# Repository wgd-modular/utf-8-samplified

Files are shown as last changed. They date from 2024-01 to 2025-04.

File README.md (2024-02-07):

# utf-8-samplified

An Arduino nano sample based 8-channel drum module for the eurorack format.

For more information on the project take a look into the [wiki](https://github.com/wgd-modular/utf-8-samplified/wiki)!



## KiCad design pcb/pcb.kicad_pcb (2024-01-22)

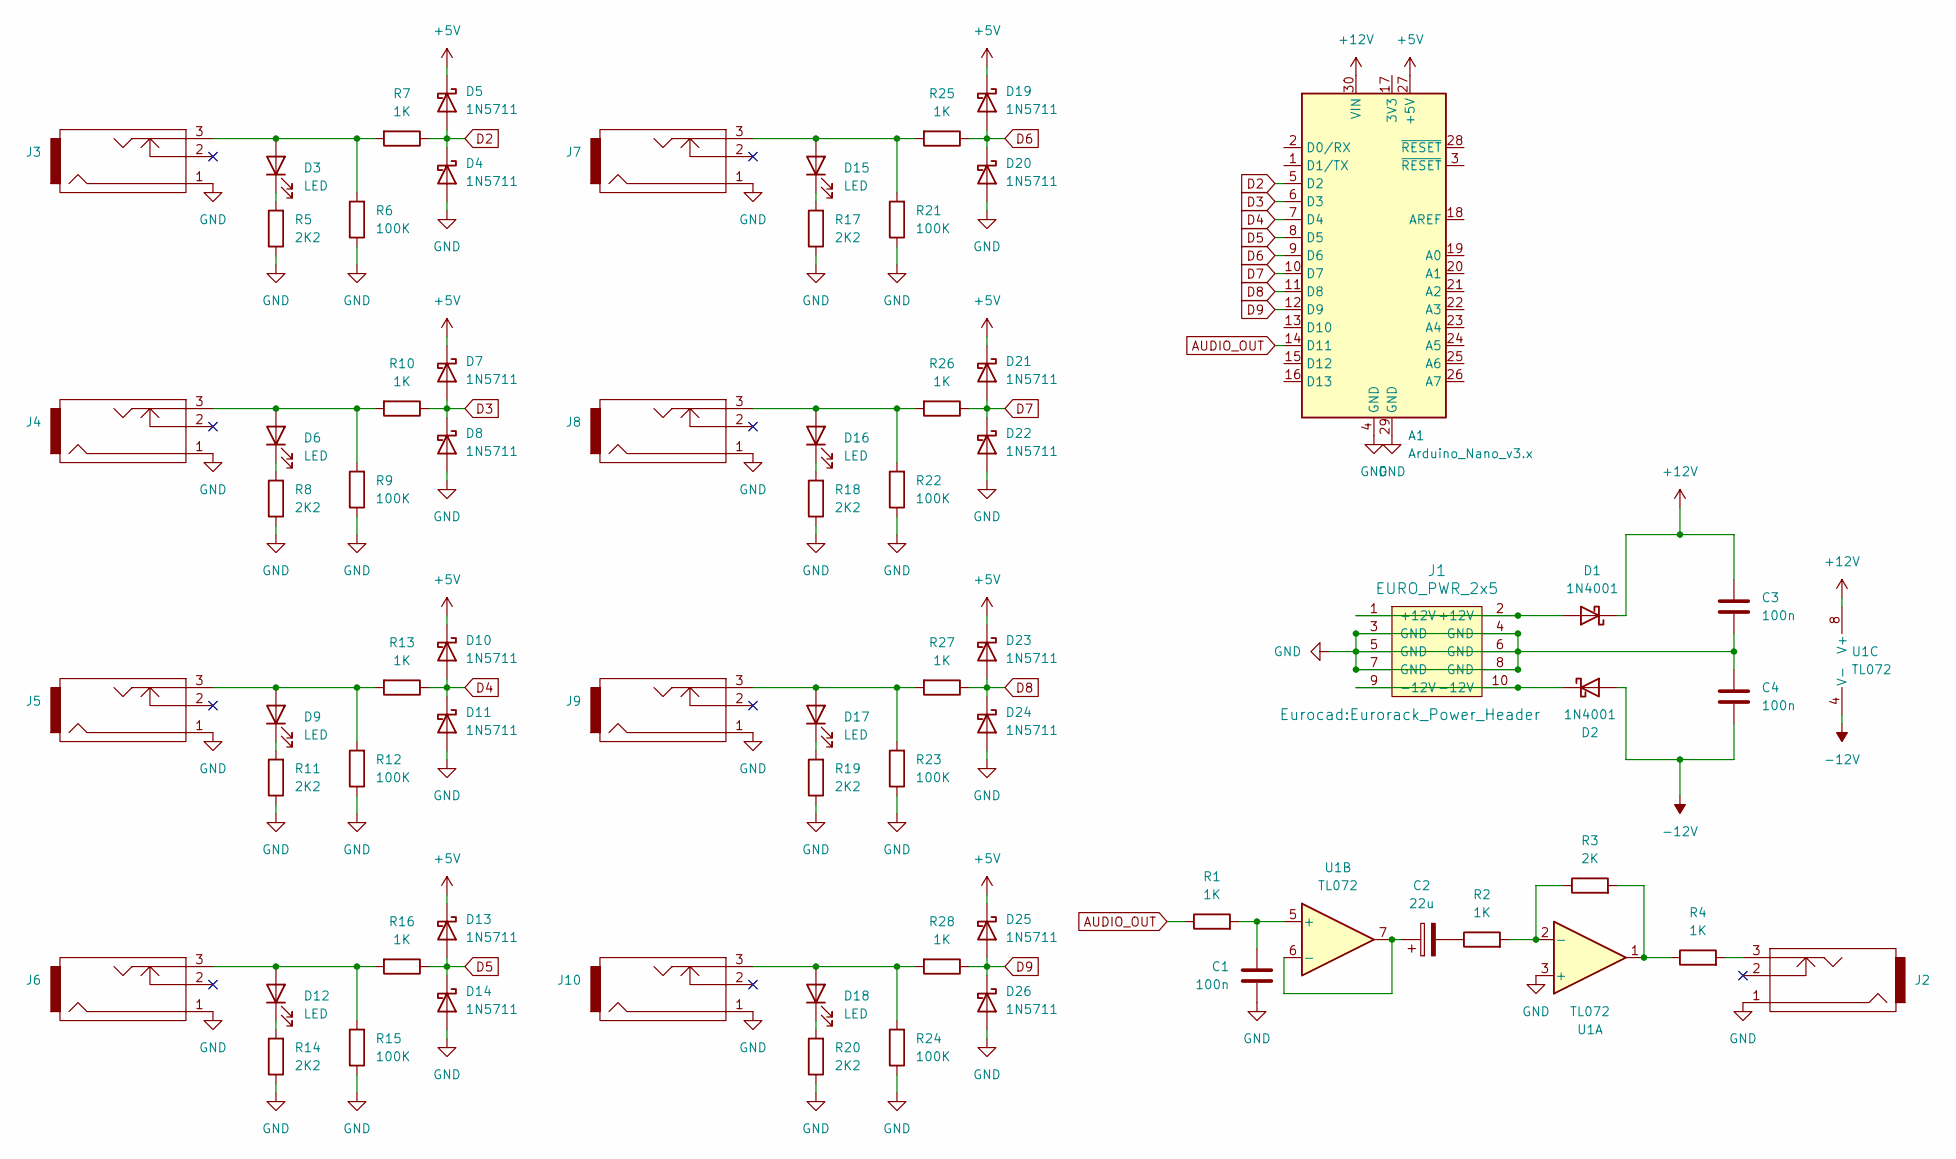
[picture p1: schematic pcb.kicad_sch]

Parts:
A1: Arduino_Nano_v3.x; Arduino_Nano
C1, C3, C4: 100n; C_Rect_L7.2mm_W3.0mm_P5.00mm_FKS2_FKP2_MKS2_MKP2
C2: 22u; CP_Radial_D5.0mm_P2.50mm
D1, D2: 1N4001; D_DO-41_SOD81_P10.16mm_Horizontal
D3, D6, D9, D12, D15, D16, D17, D18: LED; LED_D3.0mm
D4, D5, D7, D8, D10, D11, D13, D14, D19, D20, D21, D22, D23, D24, D25, D26: 1N5711; D_DO-35_SOD27_P7.62mm_Horizontal
J1: EURO_PWR_2x5; Eurorack_Power_Header
J2, J3, J4, J5, J6, J7, J8, J9, J10: PJ301M-12
R1, R2, R4, R7, R10, R13, R16, R25, R26, R27, R28: 1K; R_Axial_DIN0207_L6.3mm_D2.5mm_P7.62mm_Horizontal
R3: 2K; R_Axial_DIN0207_L6.3mm_D2.5mm_P7.62mm_Horizontal
R5, R8, R11, R14, R17, R18, R19, R20: 2K2; R_Axial_DIN0207_L6.3mm_D2.5mm_P7.62mm_Horizontal
R6, R9, R12, R15, R21, R22, R23, R24: 100K; R_Axial_DIN0207_L6.3mm_D2.5mm_P7.62mm_Horizontal
U1: TL072; DIP-8_W7.62mm

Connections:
+5V: A1.27 (+5V), D5.1 (K), D7.1 (K), D10.1 (K), D13.1 (K), D19.1 (K), D21.1 (K), D23.1 (K), D25.1 (K)
+12V: A1.30 (VIN), C3.1, D1.1 (K), U1.8 (V+)
-12V: C4.2, D2.2 (A), U1.4 (V-)
AUDIO_OUT: A1.14 (D11), R1.1
D2: A1.5 (D2), D4.1 (K), D5.2 (A), R7.1
D3: A1.6 (D3), D7.2 (A), D8.1 (K), R10.1
D4: A1.7 (D4), D10.2 (A), D11.1 (K), R13.1
D5: A1.8 (D5), D13.2 (A), D14.1 (K), R16.1
D6: A1.9 (D6), D19.2 (A), D20.1 (K), R25.1
D7: A1.10 (D7), D21.2 (A), D22.1 (K), R26.1
D8: A1.11 (D8), D23.2 (A), D24.1 (K), R27.1
D9: A1.12 (D9), D25.2 (A), D26.1 (K), R28.1
GND: A1.4 (GND), A1.29 (GND), C1.2, C3.2, C4.1, D4.2 (A), D8.2 (A), D11.2 (A), D14.2 (A), D20.2 (A), D22.2 (A), D24.2 (A), D26.2 (A), J1.3 (GND), J1.4 (GND), J1.5 (GND), J1.6 (GND), J1.7 (GND), J1.8 (GND), J2.1, J3.1, J4.1, J5.1, J6.1, J7.1, J8.1, J9.1, J10.1, R5.1, R6.1, R8.1, R9.1, R11.1, R12.1, R14.1, R15.1, R17.1, R18.1, R19.1, R20.1, R21.1, R22.1, R23.1, R24.1, U1.3 (+)
unnamed: C2.2, R2.1
unnamed: D1.2 (A), J1.1 (+12V), J1.2 (+12V)
unnamed: D2.1 (K), J1.9 (-12V), J1.10 (-12V)
unnamed: D3.2 (A), J3.3, R6.2, R7.2
unnamed: D3.1 (K), R5.2
unnamed: D6.2 (A), J4.3, R9.2, R10.2
unnamed: D6.1 (K), R8.2
unnamed: D9.2 (A), J5.3, R12.2, R13.2
unnamed: D9.1 (K), R11.2
unnamed: D12.2 (A), J6.3, R15.2, R16.2
unnamed: D12.1 (K), R14.2
unnamed: D15.2 (A), J7.3, R21.2, R25.2
unnamed: D15.1 (K), R17.2
unnamed: D16.2 (A), J8.3, R22.2, R26.2
unnamed: D16.1 (K), R18.2
unnamed: D17.2 (A), J9.3, R23.2, R27.2
unnamed: D17.1 (K), R19.2
unnamed: D18.2 (A), J10.3, R24.2, R28.2
unnamed: D18.1 (K), R20.2
unnamed: J2.3, R4.2
unnamed: R3.2, R4.1, U1.1
unnamed: R2.2, R3.1, U1.2 (-)
unnamed: C1.1, R1.2, U1.5 (+)
unnamed: C2.1, U1.6 (-), U1.7

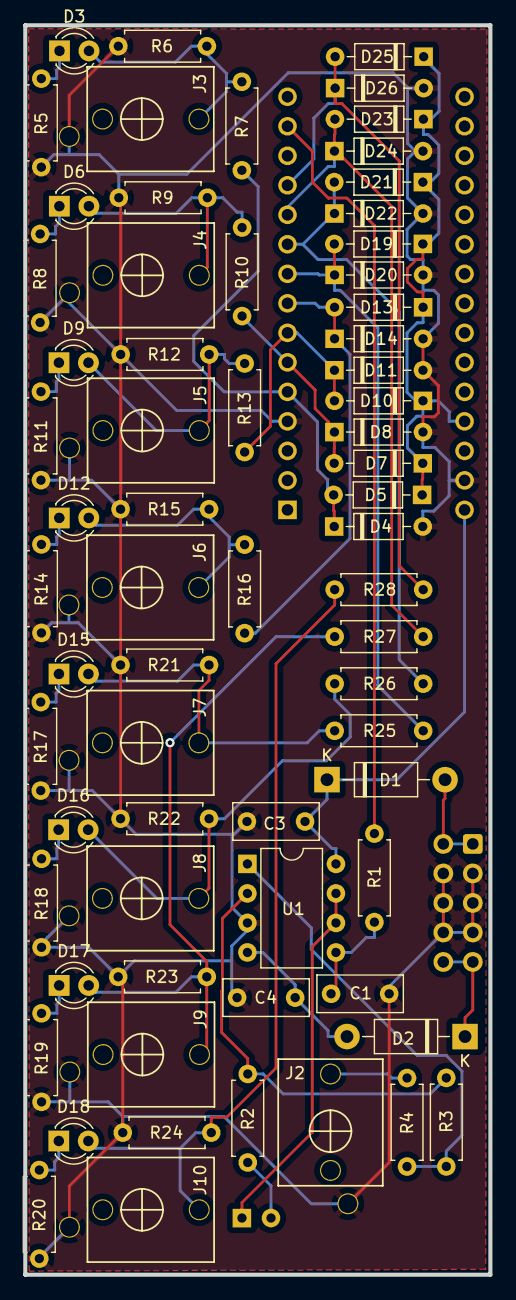
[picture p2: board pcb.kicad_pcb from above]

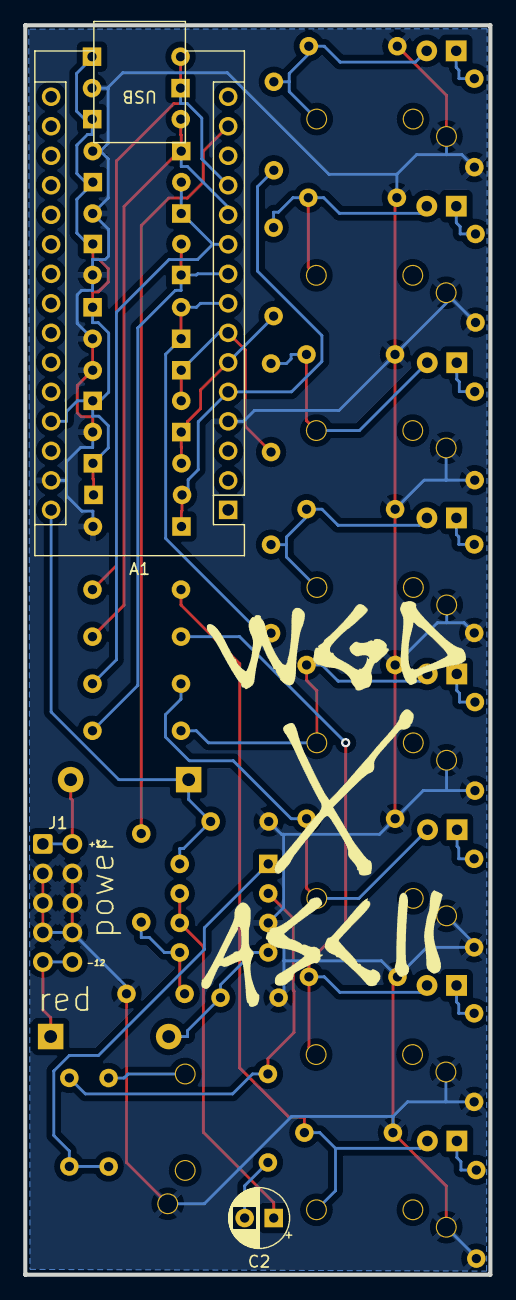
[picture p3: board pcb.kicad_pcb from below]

Board: 2 copper layers, 40.0 x 107.5 mm, 70 parts (3 on the bottom side), 37 nets.

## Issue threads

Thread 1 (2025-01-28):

Running with a LGT8F328P rather than a nano.

poetaster, 2025-01-28:
Hi! I just purchased a couple of boards (kleinanzeigen.de) and am looking forward to building this. Most of my nano projects I've moved to using a LGT8F328P running at 32MHZ (also has an 8 bit DAC and one more 16bit timer). I'm wondering if you're interested in that? I'm going to try to see how it runs, but obviously would need resample? Might be nice to have a version of utf-8 using a 'proper dac', maybe?

If you're interested, I can send you a board. There's lots of really good documenation at: https://wolles-elektronikkiste.de/en/lgt8f328p-lqfp32-boards

Thanks for the fun project!

fxwiegand, 2025-01-28:
Hi! Thanks for your interest in the project and for sharing your experience with the LGT8F328P. I’ve actually tried using these boards before, but unfortunately, I found them to be quite unreliable, so I didn’t dive deeper into them. I also discussed this with the folks at Modulove (https://modulove.io/), and they’ve had similar experiences with the LGT8F328P.

That said, it’s interesting to hear you’ve had success with them. If you do end up experimenting and resampling, I’d be curious to hear your results. Thanks again for the offer and for the kind words about the project!

poetaster, 2025-01-28:
> Hi! Thanks for your interest in the project and for sharing your experience with the LGT8F328P. I’ve actually tried using these boards before, but unfortunately, I found them to be quite unreliable, so I didn’t dive deeper into them. I also discussed this with the folks at Modulove (https://modulove.io/), and they’ve had similar experiences with the LGT8F328P.

Ah, that could be an issue with the supplier. I have a good one :) I have had one dodgy batch (3 out of 10), but have about 30 pieces (and several prototypes in use at home) in product with no complaints. I could send a known working piece or two.

> That said, it’s interesting to hear you’ve had success with them. If you do end up experimenting and resampling, I’d be curious to hear your results. Thanks again for the offer and for the kind words about the project!

I'll let you know how it stacks up when I've finished and report here. And thanks for making modules!

fxwiegand, 2025-01-29:
> I'll let you know how it stacks up when I've finished and report here. And thanks for making modules!

Actually very much looking forward to hear about your results with the LGT8F328P! Going to close this here but please keep me in the loop when you have any news.

poetaster, 2025-01-30:
Ok! So the build went smoothly. I directly went with an LGT8F328P and it all (tried all three kits), just works :) It looks like the sample rate is 40Khz and one of the timers is running at that rate. I'll try some of my own samples when I get a chance.

One note is that the module is very quiet in comparison to everything else I have in the rack.

poetaster, 2025-01-30:
Ok! So the build went smoothly. I directly went with an LGT8F328P and it all (tried all three kits), just works :) It looks like the sample rate is 40Khz and one of the timers is running at that rate. I'll try some of my own samples when I get a chance.

One note is that the module is very quiet in comparison to everything else I have in the rack.

poetaster, 2025-01-30:
> You could increase the value of R3 in the feedback loop of the op-amp to increase the gain!

R3. Bottom rightmost under D2, right?  It's 2K now, so maybe a 3.3 or  4.7K  for a start?

fxwiegand, 2025-01-30:
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

In theory 2K sets the gain of the op-amp to 2 so 3K would main a gain of 3.

poetaster, 2025-01-30:
> In theory 2K sets the gain of the op-amp to 2 so 3K would main a gain of 3.

Ok, I'll give it a go. I'll also try a resistor in parallel on one of the leds to see how that works.

poetaster, 2025-01-30:
Ok, I went with 3.9K, a notable improvement with a minimal amount more noise (4.7 was getting noisy).  Thanks!

fxwiegand, 2025-01-30:
> Ok, I went with 3.9K, a notable improvement with a minimal amount more noise (4.7 was getting noisy). Thanks!

Great to hear it worked!

Closed 2025-01-29.

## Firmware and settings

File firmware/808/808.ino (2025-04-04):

// dsp-D8 Drum Chip (c) DSP Synthesizers 2015
// Free for non commercial use

// Modified by ASCII to be triggered by digital inputs (2024)


#include <avr/interrupt.h>
#include <avr/io.h>
#include <avr/pgmspace.h>
#include "drum_samples.h"

#ifndef cbi
#define cbi(sfr, bit) (_SFR_BYTE(sfr) &= ~_BV(bit))
#endif
#ifndef sbi
#define sbi(sfr, bit) (_SFR_BYTE(sfr) |= _BV(bit))
#endif

// Standard Arduino Pins
#define digitalPinToPortReg(P) \
  (((P) >= 0 && (P) <= 7) ? &PORTD : (((P) >= 8 && (P) <= 13) ? &PORTB : &PORTC))
#define digitalPinToDDRReg(P) \
  (((P) >= 0 && (P) <= 7) ? &DDRD : (((P) >= 8 && (P) <= 13) ? &DDRB : &DDRC))
#define digitalPinToPINReg(P) \
  (((P) >= 0 && (P) <= 7) ? &PIND : (((P) >= 8 && (P) <= 13) ? &PINB : &PINC))
#define digitalPinToBit(P) \
  (((P) >= 0 && (P) <= 7) ? (P) : (((P) >= 8 && (P) <= 13) ? (P) - 8 : (P) - 14))

#define digitalReadFast(P) bitRead(*digitalPinToPINReg(P), digitalPinToBit(P))

#define digitalWriteFast(P, V) bitWrite(*digitalPinToPortReg(P), digitalPinToBit(P), (V))

const unsigned char PS_128 = (1 << ADPS2) | (1 << ADPS1) | (1 << ADPS0);

byte inputs[8] = { 2, 3, 4, 5, 6, 7, 8, 9 }; // could add , 8, 9 here..
bool prevInputStates[8] = { false, false, false, false, false, false, false, false }; // and increase this array size to 8

//--------- Ringbuf parameters ----------
uint8_t Ringbuffer[256];
uint8_t RingWrite = 0;
uint8_t RingRead = 0;
volatile uint8_t RingCount = 0;
<<<<<<< HEAD
int speakerPin = 11;
=======
>>>>>>> a4939a3c1647ea02244b6e4c8038a8c222b82560

//-----------------------------------------

ISR(TIMER1_COMPA_vect) {

  //-------------------  Ringbuffer handler -------------------------

  if (RingCount) {                            //If entry in FIFO..
    OCR2A = Ringbuffer[(RingRead++)];          //Output LSB of 16-bit DAC
    RingCount--;
  }

  //-----------------------------------------------------------------

}

bool debug = false;

<<<<<<< HEAD
/*
 * An example of how you get rid of click at end of play
 * We just make sure to not wrap around the samplecnt
ISR(TIMER1_COMPA_vect) {
   if (sample >= sounddata_length) {
       if (sample == sounddata_length + lastSample) {
           stopPlayback();
       }
       else {
           if(speakerPin==11){
               // Ramp down to zero to reduce the click at the end of playback.
               OCR2A = sounddata_length + lastSample - sample;
           } else {
               OCR2B = sounddata_length + lastSample - sample; // pin 3
           }
       }
   }
   else {
       if(speakerPin==11){
           OCR2A = Ringbuffer[(RingRead++)]; //pgm_read_byte(&sounddata_data[sample]);
       } else {
           OCR2B = Ringbuffer[(RingRead++)]; //pgm_read_byte(&sounddata_data[sample]); //pin 3
       }
   }
   RingCount--; // ++sample;
}
void stopPlayback()
{
   // Disable playback per-sample interrupt.
   TIMSK1 &= ~_BV(OCIE1A);
   // Disable the per-sample timer completely.
   TCCR1B &= ~_BV(CS10);
   // Disable the PWM timer.
   TCCR2B &= ~_BV(CS10);
   digitalWrite(speakerPin, LOW);
   
}
*/

bool debug = false;



void setup()
{
  OSCCAL = 0xFF;

=======
void setup()
{
  OSCCAL = 0xFF;

>>>>>>> a4939a3c1647ea02244b6e4c8038a8c222b82560
  for (byte i = 0; i < 6; i++) {
    pinMode(inputs[i], INPUT);
  }

  //8-bit PWM DAC pin
  pinMode(11, OUTPUT);

  // Set up Timer 1 to send a sample every interrupt.
  cli();
  // Set CTC mode
  // Have to set OCR1A *after*, otherwise it gets reset to 0!
  TCCR1B = (TCCR1B & ~_BV(WGM13)) | _BV(WGM12);
  TCCR1A = TCCR1A & ~(_BV(WGM11) | _BV(WGM10));
  // No prescaler
  TCCR1B = (TCCR1B & ~(_BV(CS12) | _BV(CS11))) | _BV(CS10);
  // Set the compare register (OCR1A).
  // OCR1A is a 16-bit register, so we have to do this with
  // interrupts disabled to be safe.
  //OCR1A = F_CPU / SAMPLE_RATE;
  // Enable interrupt when TCNT1 == OCR1A
  TIMSK1 |= _BV(OCIE1A);
  OCR1A = 400; //40KHz Samplefreq

  // Set up Timer 2 to do pulse width modulation on D11

  // Use internal clock (datasheet p.160)
  ASSR &= ~(_BV(EXCLK) | _BV(AS2));

  // Set fast PWM mode  (p.157)
  TCCR2A |= _BV(WGM21) | _BV(WGM20);
  TCCR2B &= ~_BV(WGM22);

  // Do non-inverting PWM on pin OC2A (p.155)
  // On the Arduino this is pin 11.
  TCCR2A = (TCCR2A | _BV(COM2A1)) & ~_BV(COM2A0);
  TCCR2A &= ~(_BV(COM2B1) | _BV(COM2B0));
  // No prescaler (p.158)
  TCCR2B = (TCCR2B & ~(_BV(CS12) | _BV(CS11))) | _BV(CS10);

  // Set initial pulse width to the first sample.
  OCR2A = 128;

  //set timer0 interrupt at 61Hz
  TCCR0A = 0;// set entire TCCR0A register to 0
  TCCR0B = 0;// same for TCCR0B
  TCNT0  = 0;//initialize counter value to 0
  // set compare match register for 62hz increments
  OCR0A = 255;// = 61Hz
  // turn on CTC mode
  TCCR0A |= (1 << WGM01);
  // Set CS01 and CS00 bits for prescaler 1024
  TCCR0B |= (1 << CS02) | (0 << CS01) | (1 << CS00);  //1024 prescaler

  TIMSK0 = 0;


  // set up the ADC
  ADCSRA &= ~PS_128;  // remove bits set by Arduino library
  // Choose prescaler PS_128.
  ADCSRA |= PS_128;
  ADMUX = 64;
  sbi(ADCSRA, ADSC);
  if (debug) {
    Serial.begin(115200);
    Serial.println("Modified [Jan Ostman] dsp-D8:");
    Serial.println("https://janostman.wordpress.com/the-dsp-d8-drum-chip-source-code/");
    Serial.println("Press asdfjkl; to play the drums.");
  }

  sei();
}

uint8_t phaccBD, phaccCH, phaccCL, phaccCR, phaccOH, phaccRD, phaccRS, phaccSD;
uint8_t pitchBD = 28;
uint8_t pitchCH = 28;
uint8_t pitchCL = 28;
uint8_t pitchCR = 28;
uint8_t pitchOH = 28;
uint8_t pitchRD = 28;
uint8_t pitchRS = 28;
uint8_t pitchSD = 28;
uint16_t samplecntBD, samplecntCH, samplecntCL, samplecntCR, samplecntOH, samplecntRD, samplecntRS, samplecntSD;
uint16_t samplepntBD, samplepntCH, samplepntCL, samplepntCR, samplepntOH, samplepntRD, samplepntRS, samplepntSD;

uint8_t oldPORTB;
uint8_t oldPORTD;

int16_t total;
uint8_t divider;
uint8_t MUX = 0;
char ser = ' ';

void loop()
{


  //------ Add current sample word to ringbuffer FIFO --------------------

  if (RingCount < 255) { //if space in ringbuffer
    total = 0;
<<<<<<< HEAD
    if (samplepntBD < samplecntBD) {
=======
    if (samplecntBD) {
>>>>>>> a4939a3c1647ea02244b6e4c8038a8c222b82560
      phaccBD += pitchBD;
      if (phaccBD & 128) {
        phaccBD &= 127;
        samplepntBD++;
        samplecntBD--;

      }
<<<<<<< HEAD
      ///sounddata_length + lastSample - sample;
      total += (pgm_read_byte_near(BD + samplepntBD) - 128);
    }
    if (samplepntSD < samplecntSD) {
=======
      total += (pgm_read_byte_near(BD + samplepntBD) - 128);
    }
    if (samplecntSD) {
>>>>>>> a4939a3c1647ea02244b6e4c8038a8c222b82560
      phaccSD += pitchSD;
      if (phaccSD & 128) {
        phaccSD &= 127;
        samplepntSD++;
        samplecntSD--;

      }
      total += (pgm_read_byte_near(SD + samplepntSD) - 128);
    }
<<<<<<< HEAD
    if (samplepntCL < samplecntCL) {
=======
    if (samplecntCL) {
>>>>>>> a4939a3c1647ea02244b6e4c8038a8c222b82560
      phaccCL += pitchCL;
      if (phaccCL & 128) {
        phaccCL &= 127;
        samplepntCL++;
        samplecntCL--;

      }
      total += (pgm_read_byte_near(CL + samplepntCL) - 128);
    }
<<<<<<< HEAD
    if (samplepntRS < samplecntRS) {
=======
    if (samplecntRS) {
>>>>>>> a4939a3c1647ea02244b6e4c8038a8c222b82560
      phaccRS += pitchRS;
      if (phaccRS & 128) {
        phaccRS &= 127;
        samplepntRS++;
        samplecntRS--;

      }
      total += (pgm_read_byte_near(RS + samplepntRS) - 128);
    }
<<<<<<< HEAD
    if (samplepntCH < samplecntCH) {
=======
    if (samplecntCH) {
>>>>>>> a4939a3c1647ea02244b6e4c8038a8c222b82560
      phaccCH += pitchCH;
      if (phaccCH & 128) {
        phaccCH &= 127;
        samplepntCH++;
        samplecntCH--;

      }
      total += (pgm_read_byte_near(CH + samplepntCH) - 128);
    }
<<<<<<< HEAD
    if (samplepntOH < samplecntOH) {
=======
    if (samplecntOH) {
>>>>>>> a4939a3c1647ea02244b6e4c8038a8c222b82560
      phaccOH += pitchOH;
      if (phaccOH & 128) {
        phaccOH &= 127;
        samplepntOH++;
        samplecntOH--;

      }
      total += (pgm_read_byte_near(OH + samplepntOH) - 128);
    }
<<<<<<< HEAD
    if (samplepntCR < samplecntCR) {
=======
    if (samplecntCR) {
>>>>>>> a4939a3c1647ea02244b6e4c8038a8c222b82560
      phaccCR += pitchCR;
      if (phaccCR & 128) {
        phaccCR &= 127;
        samplepntCR++;
        samplecntCR--;

      }
      total += (pgm_read_byte_near(CR + samplepntCR) - 128);
    }
<<<<<<< HEAD
    if (samplepntRD < samplecntRD) {
=======
    if (samplecntRD) {
>>>>>>> a4939a3c1647ea02244b6e4c8038a8c222b82560
      phaccRD += pitchRD;
      if (phaccRD & 128) {
        phaccRD &= 127;
        samplepntRD++;
        samplecntRD--;

      }
      total += (pgm_read_byte_near(RD + samplepntRD) - 128);
    }
    total >>= 1;
<<<<<<< HEAD
    if (!(PINB & 4)) total >>= 1; // why twice? reduces amplitude.
=======
    if (!(PINB & 4)) total >>= 1;
>>>>>>> a4939a3c1647ea02244b6e4c8038a8c222b82560
    total += 128;
    if (total > 255) total = 255;

    cli();
    Ringbuffer[RingWrite] = total;
    RingWrite++;
    RingCount++;
    sei();
  }

  //----------------------------------------------------------------------------

  //----------------- Handle Triggers ------------------------------

  bool triggered[8];
  for (byte i = 0; i < 8; i++) {
    bool currentInputState = opt_read(inputs[i]);
    triggered[i] = (currentInputState && !prevInputStates[i]);
    prevInputStates[i] = currentInputState;
  }

  if (triggered[0]) {
    samplepntBD = 0;
    samplecntBD = BDLen;
  }
  if (triggered[1]) {
    samplepntSD = 0;
    samplecntSD = SDLen;
  }
  if (triggered[2]) {
    samplepntCH = 0;
    samplecntCH = CHLen;
  }
  if (triggered[3]) {
    samplepntOH = 0;
    samplecntOH = OHLen;
  }
  if (triggered[4]) {
    samplepntRS = 0;
    samplecntRS = RSLen;
  }
  if (triggered[5]) {
    samplepntCL = 0;
    samplecntCL = CLLen;
  }
  if (triggered[6]) {
    samplepntRD = 0;
    samplecntRD = RDLen;
  }
  if (triggered[7]) {
    samplepntCR = 0;
    samplecntCR = CRLen;
  }

  //-----------------------------------------------------------------
}

bool opt_read(byte pin) {
  if (pin >= 14) {
    pin -= 14;
    return bitRead(PINC, pin);
  } else if (pin >= 8) {
    pin -= 8;
    return bitRead(PINB, pin);
  } else {
    return bitRead(PIND, pin);
  }
}

void opt_write(byte pin, bool val) {
  if (pin >= 14) {
    pin -= 14;
    bitWrite(PORTC, pin, val);
  } else if (pin >= 8) {
    pin -= 8;
    bitWrite(PORTB, pin, val);
  } else {
    bitWrite(PORTD, pin, val);
  }
}

void opt_mode(byte pin, byte val) {
  if (val == 2) {
    opt_write(pin, HIGH);
    val = 0;
  }
  if (pin >= 14) {
    pin -= 14;
    bitWrite(DDRC, pin, val);
  } else if (pin >= 8) {
    pin -= 8;
    bitWrite(DDRB, pin, val);
  } else {
    bitWrite(DDRD, pin, val);
  }
}

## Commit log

2024-01-22 Add schematic, first panel design
    [pcb.kicad_sch]
2024-01-22 Finish pcb
    [pcb.kicad_pcb, pcb.kicad_sch]
2025-04-03 And redo the fixes. (#6)
    * Fix: crush commits
    * Add: line for size of array
    * Fix: newline with fout.write
    [808.ino]
